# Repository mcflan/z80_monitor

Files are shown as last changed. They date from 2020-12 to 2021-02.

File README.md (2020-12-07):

# Z80 Monitor

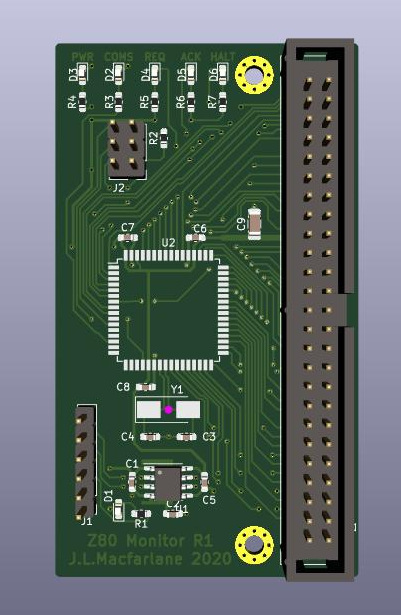
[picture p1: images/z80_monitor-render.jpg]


A device that allows a host PC to read and write memory on the bus of a Z80
computer (or potentially other CPUs) as well as a few other functions. It makes
use of the Z80's BUSRQ / BUSAK feature to gain access to the bus while the CPU
is running. The circuit is based on an Atmel atmega1281. The host interface is
a bidirectional TTL-level serial (UART) connection that uses a simple hex-based
protocol to control the monitor and provide handshaking. The host interface is
electrically isolated to allow the target device to be power-cycled properly
without being back-powered by the serial signals. This also avoids any risk of
SCR latch-up.

## Host Connector

This is 6-way single-row header to fit a standard FTDI FT232 serial cable (TTL type.) It will work with the 5V and 3V3 versions.

 | Number | Function      |
 |:------:|:------------- |
 |  6     | Not Used      |
 |  5     | Serial Out    |
 |  4     | Serial In     |
 |  3     | Power In      |
 |  2     | Not Used      |
 |  1     | Ground        |

## Bus Connector

See the [pinout file](bus_pinout.md)

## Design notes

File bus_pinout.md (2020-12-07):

# Z80 Monitor - Bus Pinout

This file describes the pinout used on the Z80 monitor board to connect it to
the target machine's bus.

## Features

 * Standard 50 way IDC header.
 * Multiple ground connections to reduce the ground inductance between boards
   and improve signal integrity.
 * Preserves as closely as possible the top-to-bottom ordering of the pins on a
   40-pin Z80 CPU to help ease PCB routing.

To make them visually equivalent to what you might find on a board, the pinout
below is shown top-down, which means the pin numbers are descending. The
two-row headers are numbered in the traditional odd-even pattern to match IDC
connector. The bus has all the data and address lines on one side and the
control signals, ground and power on the other. When placing a debug connector
on the left hand side of a PCB, the odd numbered pins will be on the right,
making them closest to the CPU. This makes routing easier on prototyping boards
or strip-boards.

## Debug Bus

| Number | Function | Number | Function |
|:---:|:--- |:---:|:--- |
| 50 | GND | 49 | A15 |
| 48 | /RFSH  RSVD2 | 47 | A14 |
| 46 | RSVD1 | 45 | A13 |
| 44 | GND | 43 | A12 |
| 42 | /BUSRQ | 41 | A11 |
| 40 | /BUSAK | 39 | A10 |
| 38 | /HALT | 37 | A9 |
| 36 | /MREQ | 35 | A8 |
| 34 | GND | 33 | A7 |
| 32 | +5V | 31 | A6 |
| 30 | +5V | 29 | A5 |
| 28 | RSVD0 | 27 | A4 |
| 26 | /NMI | 25 | A3 |
| 24 | GND | 23 | A2 |
| 22 | /INT | 21 | A1 |
| 20 | /WAIT | 19 | A0 |
| 18 | GND | 17 | GND |
| 16 | /RESET | 15 | D7 |
| 14 | CLK | 13 | D6 |
| 12 | GND | 11 | D5 |
| 10 | /M1 |  9 | D4 |
|  8 | /WR |  7 | D3 |
|  6 | /RD |  5 | D2 |
|  4 | /IORQ |  3 | D1 |
|  2 | GND |  1 | D0 |

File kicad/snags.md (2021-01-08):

# Snag list for PCB

LEDs should be 0805 footprint. Having said that, the 0805 LEDs do seem to fit
reasonably well. We could just order 0603 LEDs instead?

Probably could have done something more useful with CLK pin than just leaving
unconnected, .e.g connect to a timer input so we could measure clock speed?

Consider adding Neopixel for target status (e.g. HALT, etc.?)

Consider changing bus connector to right-angle PCB-mount socket, for direct
connection to target (or via male-female IDC ribbon cable.)

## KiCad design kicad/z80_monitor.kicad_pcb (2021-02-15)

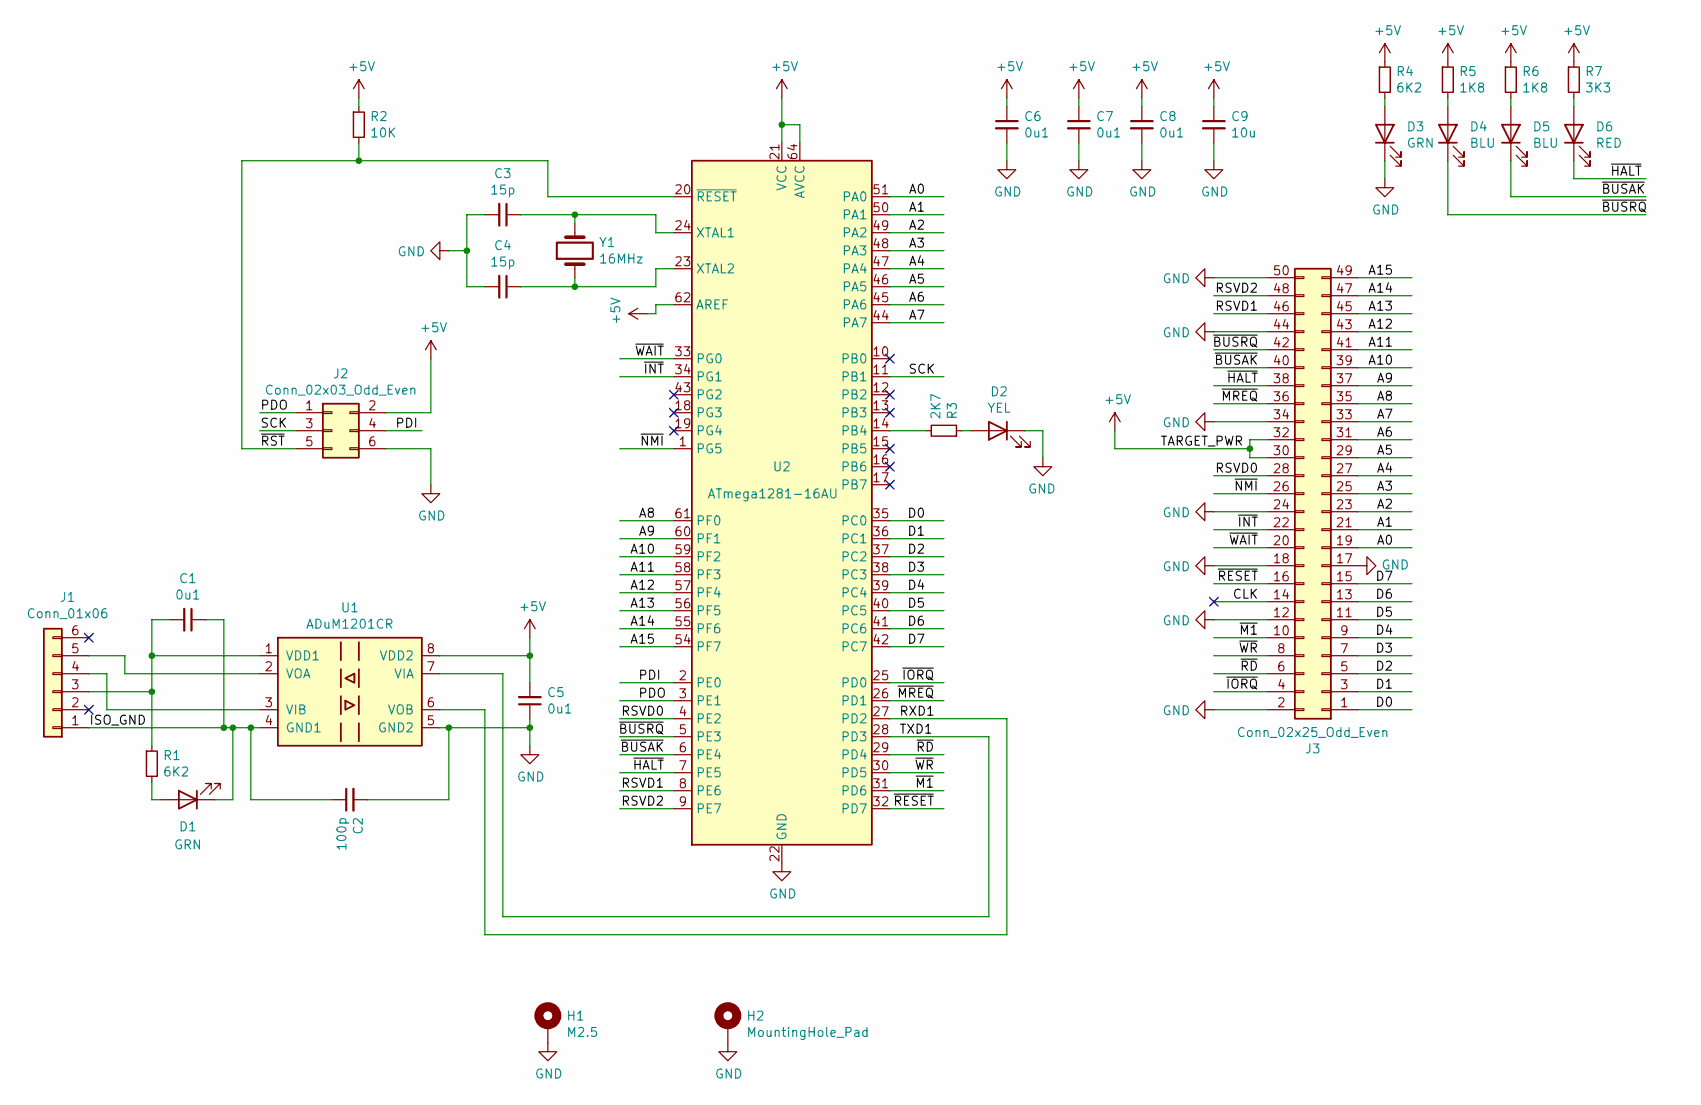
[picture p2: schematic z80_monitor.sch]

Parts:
C1, C5, C6, C7, C8: 0u1; C_0603_1608Metric_Pad1.05x0.95mm_HandSolder
C2: 100p; C_0603_1608Metric_Pad1.05x0.95mm_HandSolder
C3, C4: 15p; C_0603_1608Metric_Pad1.05x0.95mm_HandSolder
C9: 10u; C_1206_3216Metric_Pad1.42x1.75mm_HandSolder
D1, D3: GRN; LED_0603_1608Metric_Pad1.05x0.95mm_HandSolder
D2: YEL; LED_0603_1608Metric_Pad1.05x0.95mm_HandSolder
D4, D5: BLU; LED_0603_1608Metric_Pad1.05x0.95mm_HandSolder
D6: RED; LED_0603_1608Metric_Pad1.05x0.95mm_HandSolder
H1: M2.5; MountingHole_2.7mm_M2.5_Pad_Via
H2: MountingHole_Pad; MountingHole_2.7mm_M2.5_Pad_Via
J1: Conn_01x06; PinHeader_1x06_P2.54mm_Vertical
J2: Conn_02x03_Odd_Even; PinHeader_2x03_P2.54mm_Vertical
J3: Conn_02x25_Odd_Even; IDC-Header_2x25_P2.54mm_Vertical
R1, R4: 6K2; R_0603_1608Metric_Pad1.05x0.95mm_HandSolder
R2: 10K; R_0603_1608Metric_Pad1.05x0.95mm_HandSolder
R3: 2K7; R_0603_1608Metric_Pad1.05x0.95mm_HandSolder
R5, R6: 1K8; R_0603_1608Metric_Pad1.05x0.95mm_HandSolder
R7: 3K3; R_0603_1608Metric_Pad1.05x0.95mm_HandSolder
U1: ADuM1201CR; SOIC-8_3.9x4.9mm_P1.27mm
U2: ATmega1281-16AU; TQFP-64_14x14mm_Pitch0.8mm; Farnell 1455092
Y1: 16MHz; Crystal_SMD_Abracon_ABM3-2Pin_5.0x3.2mm_HandSoldering; Farnell 2467791

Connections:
+5V: C5.2, C6.1, C7.1, C8.1, C9.1, J2.2, J3.30, J3.32, R2.1, R4.1, R5.1, R6.1, R7.1, U1.8 (VDD2), U2.21 (VCC), U2.52 (VCC), U2.62 (AREF), U2.64 (AVCC)
/A0: J3.19, U2.51 (PA0)
/A1: J3.21, U2.50 (PA1)
/A2: J3.23, U2.49 (PA2)
/A3: J3.25, U2.48 (PA3)
/A4: J3.27, U2.47 (PA4)
/A5: J3.29, U2.46 (PA5)
/A6: J3.31, U2.45 (PA6)
/A7: J3.33, U2.44 (PA7)
/A8: J3.35, U2.61 (PF0)
/A9: J3.37, U2.60 (PF1)
/A10: J3.39, U2.59 (PF2)
/A11: J3.41, U2.58 (PF3)
/A12: J3.43, U2.57 (PF4)
/A13: J3.45, U2.56 (PF5)
/A14: J3.47, U2.55 (PF6)
/A15: J3.49, U2.54 (PF7)
/CLK: J3.14
/D0: J3.1, U2.35 (PC0)
/D1: J3.3, U2.36 (PC1)
/D2: J3.5, U2.37 (PC2)
/D3: J3.7, U2.38 (PC3)
/D4: J3.9, U2.39 (PC4)
/D5: J3.11, U2.40 (PC5)
/D6: J3.13, U2.41 (PC6)
/D7: J3.15, U2.42 (PC7)
/ISO_GND: C1.1, C2.1, D1.1 (K), J1.1, U1.4 (GND1)
/PDI: J2.4, U2.2 (PE0)
/PDO: J2.1, U2.3 (PE1)
/RSVD0: J3.28, U2.4 (PE2)
/RSVD1: J3.46, U2.8 (PE6)
/RSVD2: J3.48, U2.9 (PE7)
/RXD1: U1.6 (VOB), U2.27 (PD2)
/SCK: J2.3, U2.11 (PB1)
/TXD1: U1.7 (VIA), U2.28 (PD3)
/~BUSAK~: D5.1 (K), J3.40, U2.6 (PE4)
/~BUSRQ~: D4.1 (K), J3.42, U2.5 (PE3)
/~HALT~: D6.1 (K), J3.38, U2.7 (PE5)
/~INT~: J3.22, U2.34 (PG1)
/~IORQ~: J3.4, U2.25 (PD0)
/~M1~: J3.10, U2.31 (PD6)
/~MREQ~: J3.36, U2.26 (PD1)
/~NMI~: J3.26, U2.1 (PG5)
/~RD~: J3.6, U2.29 (PD4)
/~RESET~: J3.16, U2.32 (PD7)
/~RST~: J2.5, R2.2, U2.20 (~RESET)
/~WAIT~: J3.20, U2.33 (PG0)
/~WR~: J3.8, U2.30 (PD5)
GND: C2.2, C3.2, C4.2, C5.1, C6.2, C7.2, C8.2, C9.2, D2.1 (K), D3.1 (K), H1.1, H2.1, J2.6, J3.2, J3.12, J3.17, J3.18, J3.24, J3.34, J3.44, J3.50, U1.5 (GND2), U2.22 (GND), U2.53 (GND), U2.63 (GND)
unnamed: C1.2, J1.3, R1.1, U1.1 (VDD1)
unnamed: C3.1, U2.24 (XTAL1), Y1.2
unnamed: C4.1, U2.23 (XTAL2), Y1.1
unnamed: D1.2 (A), R1.2
unnamed: D2.2 (A), R3.1
unnamed: D3.2 (A), R4.2
unnamed: D4.2 (A), R5.2
unnamed: D5.2 (A), R6.2
unnamed: D6.2 (A), R7.2
unnamed: J1.4, U1.3 (VIB)
unnamed: J1.5, U1.2 (VOA)
unnamed: R3.2, U2.14 (PB4)

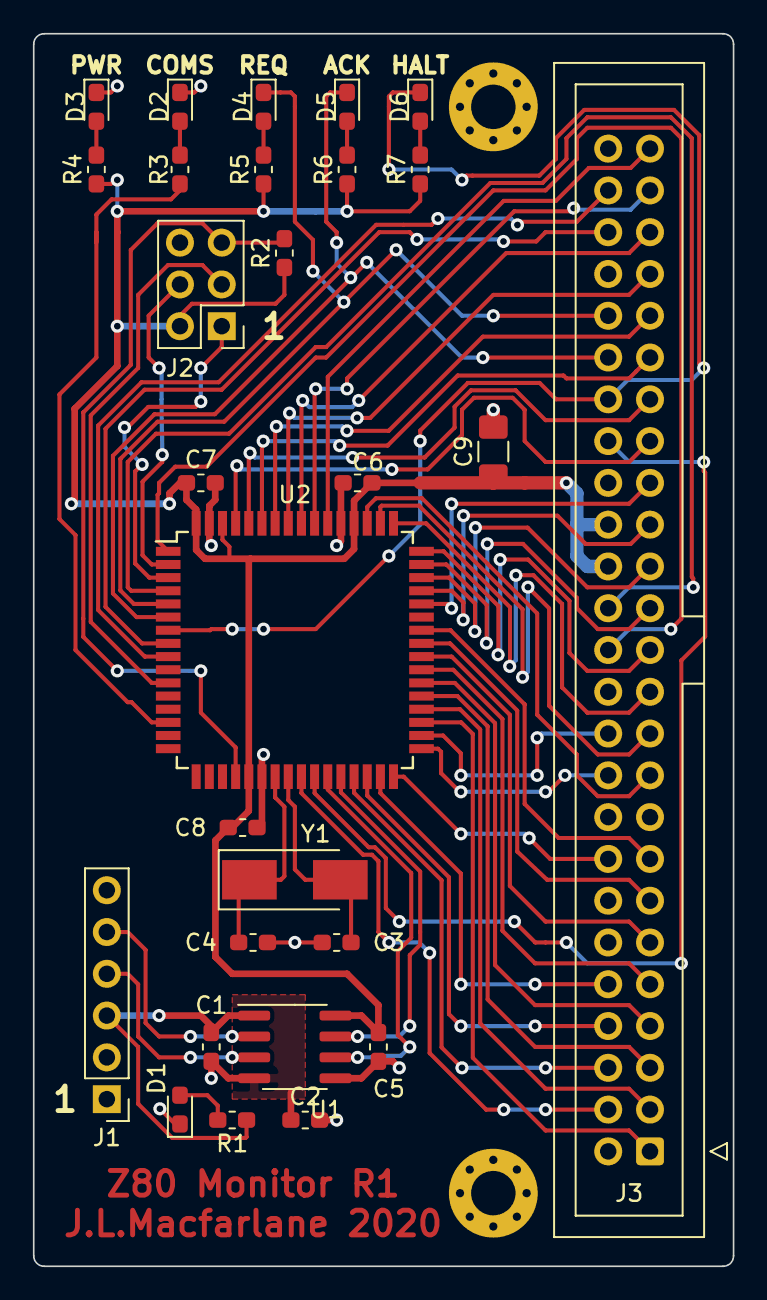
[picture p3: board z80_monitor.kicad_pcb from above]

Board: 2 copper layers, 42.5 x 74.9 mm, 30 parts (0 on the bottom side), 60 nets.

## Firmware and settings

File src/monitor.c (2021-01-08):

/*
 * Z80 Monitor board driver
 *
 * (C) Copyright James L Macfarlane, Airborne Engineering Ltd 2020.
 */

#include "board.h"

#include <avr/io.h>
#include <avr/interrupt.h>
#include <util/delay.h>
#include <avr/io.h>
#include <avr/sleep.h>
#include <avr/pgmspace.h>
#include <avr/eeprom.h>
#include <avr/sleep.h>
#include <avr/cpufunc.h>

#include <stdbool.h>
#include <stdint.h>
#include <stdlib.h>
#include <string.h>
#include <ctype.h>
#include <stdio.h>
#include <math.h>

#include "uart.h"
#include "timer.h"
#include "debug.h"
#include "hexify.h"
#include "poll.h"
#include "monitor.h"

hexify_encoder_t henc;
hexify_decoder_t hdec;

#if defined(GIT_VERSION) && defined(GIT_DATE)
/* Version message */
    #define VERSION_MSG  "# Firmware git hash " GIT_VERSION " " GIT_DATE " Build " __DATE__ " " __TIME__ "\n\n\r"
#else
    #error "GIT_VERSION and/or GIT_DATE not defined."
#endif

#ifdef DEBUG
    uint8_t debug_lvl = 1;
#endif

void set_reset(bool state);
void set_INT(bool state);
void set_NMI(bool state);
void set_BUSRQ(bool state);
void bus_enable(bool state);

led_t leds[LEDS_NUMOF] = {
    [COMS_LED] = { .port = &LED_PORT, .pin = COMS_LED_PIN },
};

/*
 * Sleep a number of seconds using interrupt-driven timer.
 */
void wait(float t)
{
    timer_start(ST_WAIT, TIMER_MODE_ONESHOT, RATE(t));
    timer_sleep(ST_WAIT);
}

hexify_decoder_t decoder;


static inline void set_reg_addr(uint8_t x)
{
    PORTC &= ~0x03;
    PORTC |= x & 0x03;
    _NOP(); _NOP(); _NOP(); _NOP();
}

static inline void write_cycle(uint16_t addr, uint8_t memtype, uint8_t data)
{
    // Set-up address and data lines
    DA_DDR = 0xff;  // Enable data lines
    AL_PORT = addr & 0xff;
    AH_PORT = addr >> 8;
    DA_PORT = data;
    _NOP(); _NOP();
    // Set handshake lines
    if (memtype == MEM_TYPE_IO) {
        CTRL_PORT = MREQ | RD | M1 | RESET; // IORQ & WR low
    } else {
        CTRL_PORT = IORQ | RD | M1 | RESET; // MREQ & WR low
    }
    _NOP(); _NOP(); _NOP(); _NOP(); _NOP(); _NOP(); // Approx 0.5us
    CTRL_PORT = IORQ | MREQ | RD | WR | M1 | RESET; // De-assert everything
    _NOP(); _NOP(); _NOP(); _NOP(); _NOP(); _NOP(); // Approx 0.5us
    DA_DDR = 0x00;  // Disable data lines
}

static inline uint8_t read_cycle(uint16_t addr, uint8_t memtype)
{
    // Set-up address lines
    DA_DDR = 0x00;  // Ensure data port dir is in
    AL_PORT = addr & 0xff;
    AH_PORT = addr >> 8;
    _NOP(); _NOP();
    // Set handshake lines
    if (memtype == MEM_TYPE_IO) {
        CTRL_PORT = MREQ | WR | M1 | RESET; // IORQ & RD low
    } else {
        CTRL_PORT = IORQ | WR | M1 | RESET; // MREQ & RD low
    }
    _NOP(); _NOP(); _NOP(); _NOP(); _NOP(); _NOP(); // Approx 0.5us
    uint8_t x = DA_PIN; // Read data bus
    CTRL_PORT = IORQ | MREQ | RD | WR | M1 | RESET; // De-assert everything
    _NOP(); _NOP(); _NOP(); _NOP(); _NOP(); _NOP(); // Approx 0.5us
    return x;
}

static inline void write_block(uint16_t addr, uint8_t memtype, uint8_t *data, int size)
{
    int i;
    for (i = 0; i < size; i++) {
        write_cycle(addr++, memtype, data[i]);
    }
}

static inline void clear_block(uint16_t addr, uint8_t memtype, unsigned int size, uint8_t value)
{
    unsigned int i;
    for (i = 0; i < size; i++) {
        write_cycle(addr++, memtype, value);
    }
}

static inline void read_block(uint16_t addr, uint8_t memtype, uint8_t *data, int size)
{
    int i;
    for (i = 0; i < size; i++) {
        data[i] = read_cycle(addr++, memtype);
    }
}

typedef struct mon_s {
    uint16_t addr;
    uint8_t bus_claimed;
    uint8_t view_on;
    uint8_t mem_type;
    int cmd;
    int count;
    int buf_ptr;
} mon_t;

void mon_init(mon_t *mon)
{
    mon->bus_claimed = 0;
    mon->mem_type = 0; // Default to main memory
    mon->buf_ptr = 0;
}

#define RD_BUF_SIZE     (32)
static uint8_t rd_buf[RD_BUF_SIZE];

void do_msg(mon_t *mon, uint8_t type, int len, uint8_t *data)
{
    switch (type) {
        case MSG_WR: {
            // type(1), memtype(1), address(2), data(N), checksum(1)
            int size = len - 3;
            if (size < 0) {
                printf("# Not enough bytes (%d) for message type %d\n", len, type);
                break;
            }
            uint8_t memtype = data[0];
            uint16_t addr = data[1] | (data[2] << 8);
            printf("# Writing %2d bytes at 0x%04X - ", size, addr);
            write_block(addr, memtype, data+3, size);
            read_block(addr, memtype, rd_buf, size);
            int i;
            for (i = 0; i < size; i++) {
                if ((data+3)[i] != rd_buf[i]) break;
            }
            if (i < size) {
                printf("Error at 0x%04X\n", addr+i);
            } else {
                printf("ok\n");
            }
            break;
        }
        case MSG_RD: {
            uint8_t memtype = data[0];
            uint16_t addr = data[1] | (data[2] << 8);
            int size = data[3];
            if (size > (RD_BUF_SIZE-2)) {
                printf("# Can't read more than %d bytes at a time\n", RD_BUF_SIZE-2);
                break;
            }
            rd_buf[0] = addr & 0xff;
            rd_buf[1] = addr >> 8;
            read_block(addr, memtype, rd_buf+2, size);
            hexify_sender_start(&henc, MSG_RD, rd_buf, size+2);
            char c;
            while  (hexify_sender_next(&henc, &c)) cdev_put(COM_CDEV, c);
            break;
        }
        case MSG_CLEAR: {
            uint8_t memtype = data[0];
            uint16_t addr = data[1] | (data[2] << 8);
            uint16_t size = data[3] | (data[4] << 8);
            int value = data[5];
            printf("# Starting at 0x%04X, clear %5u bytes to value 0x%02X\n", addr, size, value);
            clear_block(addr, memtype, size, value);
            break;
        }
        case MSG_BUS_REQ:
            printf("# Acquire bus\n");
            set_BUSRQ(true);
            _delay_us(100); // Wait 100us for BUSAK
            if ((PINE & BUSAK) == 0) {
                bus_enable(true);
            }
            break;
        case MSG_BUS_REL:
            printf("# Release bus\n");
            bus_enable(false);
            set_BUSRQ(false);
            break;
        case MSG_RESET:
            printf("# Reset and release\n");
            set_reset(true);
            _delay_us(100);
            bus_enable(false);
            set_BUSRQ(false);
            _delay_ms(50);
            set_reset(false);
            break;
        case MSG_NMI:
            printf("# NMI\n");
            set_NMI(true);
            _delay_us(50);
            set_NMI(false);
            break;
        case MSG_INT:
            printf("# INT\n");
            set_INT(true);
            _delay_us(50);
            set_INT(false);
            break;
        default:
            printf("# Don't know about msg type %2d\n", type);
    }
}

#define MSG_BUF_SIZE     (64)
static uint8_t msgbuf[MSG_BUF_SIZE];

static void main_loop(mon_t *mon)
{
    mon_init(mon);
    hexify_recvr_init(&hdec, msgbuf, MSG_BUF_SIZE);
    // Wait for a message to arrive then process it
    while (1) {
        uint8_t type;
        int len;
        char c = cdev_get(COM_CDEV);
        int ret = hexify_recvr_next(&hdec, c, &type, &len);
        if (ret == 0) {
            led_once(COMS_LED, RATE(0.1));
            do_msg(mon, type, len, msgbuf);
        }
        if (ret < 0) {
            led_once(COMS_LED, RATE(0.02));
            printf("# Hex encoding error %d\n", ret);
        }
    }
}

static mon_t mon;


void set_reset(bool state)
{
    if (state) {
        // Simulate an open-collector output
        CTRL_PORT &= ~RESET;
        CTRL_DDR |= RESET;
    } else {
        CTRL_PORT |= RESET; // Enable pull-up
        CTRL_DDR &= ~RESET;
    }
}

void set_INT(bool state)
{
    if (state) {
        PORTG &= ~INT;
        DDRG |= INT;
    } else {
        PORTG |= INT; // Enable pull-up
        DDRG &= ~INT;
    }
}

void set_NMI(bool state)
{
    if (state) {
        PORTG &= ~NMI;
        DDRG |= NMI;
    } else {
        PORTG |= NMI; // Enable pull-up
        DDRG &= ~NMI;
    }
}

void set_BUSRQ(bool state)
{
    if (state) {
        PORTE &= ~BUSRQ;
    } else {
        PORTE |= BUSRQ;
    }
}

void bus_enable(bool state)
{
    if (state) {
        AL_DDR = 0xff;
        AH_DDR = 0xff;
        CTRL_DDR = IORQ | MREQ | RD | WR | M1;
    } else {
        AL_DDR = 0;
        AH_DDR = 0;
        DA_DDR = 0;
        CTRL_DDR = 0;
        CTRL_PORT = IORQ | MREQ | RD | WR | M1; // Enable pull-ups
    }
}


void init_io(void)
{
    MCUCR |= PUD;
    // Tri-state All the Things
    DDRA = 0;
    DDRB = 1 << COMS_LED_PIN;
    DDRC = 0;
    DDRD = 0;
    PORTE = BUSRQ;  // Ensure /BUSRQ is off 
    DDRE = BUSRQ;
    DDRF = 0;
    PORTG = WAIT;
    DDRG = 0;
    CTRL_PORT = IORQ | MREQ | RD | WR | M1;
}

int main(void)
{
    init_io(); // Get all I/O pins in correct state & direction

    timer_init(TIMER1_RELOAD);

    led_init(leds, LEDS_NUMOF);

    /* turn on global interrupts */
    sei();

    //usart1_init(COM_CDEV, 8); /* 230400 baud - this doesn't receive well enough to cope with adjacent bytes */
    //usart1_init(COM_CDEV, 1); /* 1M baud */
    usart1_init(COM_CDEV, 16); /* 115200 baud */
    stdout = &usart1_fp;

    cdev_put(COM_CDEV, '\n');
    cdev_put(COM_CDEV, '\r');
    PRINT("# MCU Monitor. J.Macfarlane 2020\n\r");
    PRINT(VERSION_MSG);

    main_loop(&mon);

    return 0;
}

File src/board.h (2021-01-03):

#ifndef BOARD_H
#define BOARD_H

/* CPU frequency */
#define F_CPU 16000000UL

#include <avr/io.h>

#define COM_CDEV                   (UART1_CDEV)

/* timing */

/* Main timer - 100 Hz */
#define TIMER1_PRESCALE             (8)
#define TIMER1_RATE                 (100)
#define TIMER1_RELOAD               (F_CPU/TIMER1_PRESCALE/TIMER1_RATE)

#define RATE(x) (x * TIMER1_RATE)


/* soft timer designations */
#define ST_UART                     (0)
#define ST_WAIT                     (1)
#define ST_LED                      (2)
#define ST_FIX                      (3)


/* I/O pins */
#define AL_PORT                     (PORTA)
#define AL_DDR                      (DDRA)
#define AH_PORT                     (PORTF)
#define AH_DDR                      (DDRF)

#define DA_PORT                     (PORTC)
#define DA_PIN                      (PINC)
#define DA_DDR                      (DDRC)

#define CTRL_PORT                   (PORTD)
#define CTRL_PIN                    (PIND)
#define CTRL_DDR                    (DDRD)

#define IORQ                        (1 << PD0)
#define MREQ                        (1 << PD1)
#define RXD1                        (1 << PD2)
#define TXD1                        (1 << PD3)
#define RD                          (1 << PD4)
#define WR                          (1 << PD5)
#define M1                          (1 << PD6)
#define RESET                       (1 << PD7)

#define RSVD0                       (1 << PE2)
#define BUSRQ                       (1 << PE3)
#define BUSAK                       (1 << PE4)
#define HALT                        (1 << PE5)
#define RSVD1                       (1 << PE6)
#define RSVD2                       (1 << PE7)

#define WAIT                        (1 << PG0)
#define INT                         (1 << PG1)
#define NMI                         (1 << PG5)

#define LEDS_NUMOF                  (1)
#define LED_PORT                    (PORTB)
#define COMS_LED                    (0)
#define COMS_LED_PIN                (4)


enum {
    MEM_TYPE_MEM = 0,
    MEM_TYPE_IO = 1,
};



/* ADC - Vref is set by an external reference as of PCB Rev.4 */
#define VREF                        (2.500)
#define ADC_BITS                    (10)
/* divide by 64, which gives 125KHz ADC clock for 8MHZ xtal */
#define ADC_CLOCK_DIVIDER (6)

char sleep_read(int fd, int timeout);

#endif /* BOARD_H */

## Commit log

2020-10-28 Add kicad schematic - still work-in-progress.
    [cpu_mem_board.sch, io_board.sch, psu_board.sch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]
2020-10-29 UART section of IO board completed.
    [baud_clock.sch, cpu_mem_board.sch, io_board.sch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]
2020-10-29 Lots more work on schematic
    [baud_clock.sch, cpu_mem_board.sch, io_board.sch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]
2020-10-29 Name sheets.
    [io_board.sch, z80_mk_II_schematic.sch]
2020-10-29 Un-fsck something which made most of the chips into 74LS00 for some very odd reason. Also start to assign footprints.
    [baud_clock.sch, cpu_mem_board.sch, io_board.sch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]
2020-10-30 Re-annotateand fix doubled-up U6 unit.
    [cpu_mem_board.sch, io_board.sch, psu_board.sch]
2020-10-30 Add some no-connection symbols.
    [baud_clock.sch, cpu_mem_board.sch, io_board.sch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]
2020-10-30 Add missing connection for /wait.
    [cpu_mem_board.sch]
2020-10-30 Add some missing gates and wiring.
    [baud_clock.sch, cpu_mem_board.sch, io_board.sch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]
2020-10-30 Complete RAM_WR_EN wiring.
    [io_board.sch, z80_mk_II_schematic.sch]
2020-10-30 Add pull-up for /IORQ on IO board.
    [io_board.sch]
2020-10-30 Add eagle files for old z80 monitor board and for mods to make it compatible with new 50 way pinout.
    [james_z80_debug.brd, james_z80_debug.sch, james_z80_debug_mod.brd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]
2020-10-30 Add adapter board for old monitor eurocard connector to new 50 way pinout.
    [adapter.sch]
2020-10-31 Update monitor mods.
    [james_z80_debug_mod.brd, james_z80_debug_mod.sch]
2020-10-31 Update to adapter.
    [adapter.sch]
2020-11-05 Add a label to eagle schematics.
    [james_z80_debug_mod.brd, james_z80_debug_mod.sch]
2020-11-05 Add beginings of arduino monitor code.
2020-11-14 Add kicad schematic and rough veroboard layout for raspi floppy interface.
    [raspi_floppy.kicad_pcb, raspi_floppy.sch]
2020-11-16 Add missing resnet for keyboard pull-ups.
    [io_board.sch]
2020-11-18 Add freeCAD drawing of spacer.
    [spacers.FCStd]
2020-11-18 Update Pi floppy i/f.
    [raspi_floppy.kicad_pcb, raspi_floppy.sch]
2020-11-18 Minor update to schematic.
    [io_board.sch, uart.sch]
2020-11-18 Move mkII schematic dir.
    [baud_clock.sch, cpu_mem_board.sch, io_board.sch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]
2020-11-18 Add g-code for spacer top machining.
2020-11-18 Rename a dir.
    [spacers.FCStd]
2020-11-21 Increase amount to remove in finishing cut to try to re-cut the chips less.
2020-11-22 Fix library path for adapter after moving mkII schematic dir.
2020-11-22 Add note to CPU schematic.
    [cpu_mem_board.sch]
2020-11-30 Change of plan: get rid of interactive terminal and instead us code on host. This solves problem of flow-control. Add header for magic numbers shared with host monitor code.
    [monitor.c]
2020-11-30 Fix pretty-printing.
2020-11-30 Fix cmd line help.
    [monitor.py]
2020-12-03 Add kicad project for new monitor board.
    [bus_driver.sch, monitor.sch]
2020-12-03 Assign some footprints and begin to play with layout
    [bus_driver.sch, z80_monitor.kicad_pcb, z80_monitor.sch]
2020-12-03 More updates.
    [bus_driver.sch, z80_monitor.kicad_pcb, z80_monitor.sch]
2020-12-03 Add new minimalist atmega1281-bases monitor.
    [z80_monitor.kicad_pcb, z80_monitor.sch]
2020-12-06 Finished new AVR-based monitor board, pending final checks and gerber generation.
    [z80_monitor.kicad_pcb, z80_monitor.sch]
2020-12-06 Move LEDs to edge of board and label. Add 2x M2.5 clearance hole.
    [z80_monitor.kicad_pcb]
2020-12-07 Various updates to board.
    [z80_monitor.kicad_pcb, z80_monitor.sch]
2020-12-07 Minor updates.
    [z80_monitor.kicad_pcb]
2020-12-07 More re-arrangement of files.
    [z80_monitor.kicad_pcb, z80_monitor.sch]
2020-12-07 Add gerbers
    [z80_monitor-B_Cu.gbr, z80_monitor-B_Mask.gbr, z80_monitor-B_Paste.gbr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]
2020-12-07 Re-do gerbers with new settings.
    [z80_monitor-B_Cu.gbl, z80_monitor-B_Mask.gbs, z80_monitor-B_Paste.gbr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]
2020-12-07 Update gerbers.
    [z80_monitor-B_Cu.gbl, z80_monitor-B_Mask.gbs, z80_monitor-B_SilkS.gbo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]
2021-01-03 Update LED resistor values to try to match brightness.
    [z80_monitor.sch]
2021-01-03 230400 baud doesn't rx properly. Changed to 115200.
    [monitor.c, monitor.py]
2021-01-04 Add code to flush serial input buf in python. Add reset and release functionality.
    [monitor.c, monitor.py]
2021-01-04 Add snag list for PCB.
2021-02-15 Update board
    [z80_monitor.kicad_pcb]
